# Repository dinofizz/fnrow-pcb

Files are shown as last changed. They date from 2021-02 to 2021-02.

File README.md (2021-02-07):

# FnRow

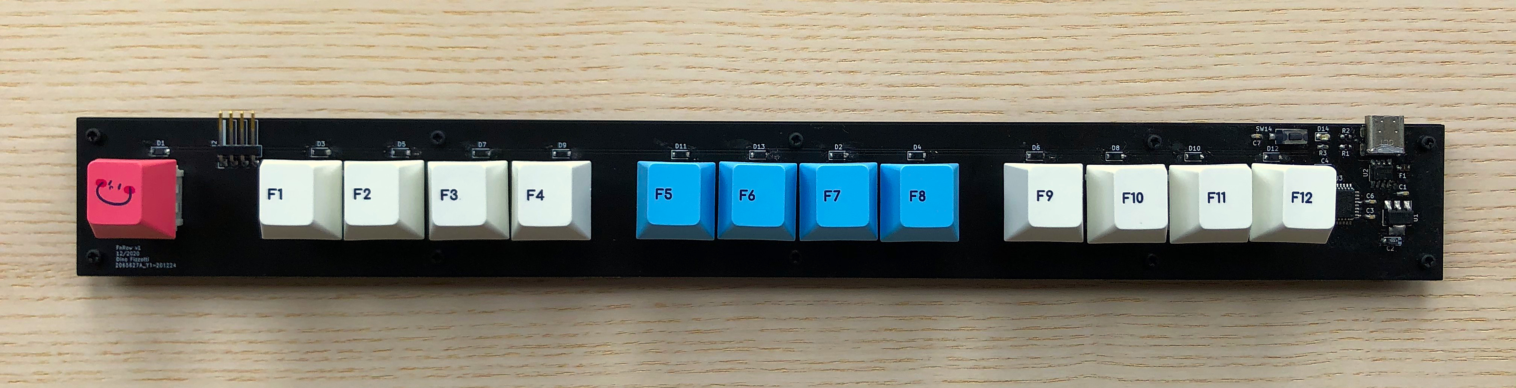
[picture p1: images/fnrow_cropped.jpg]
FnRow


FnRow is a mechanical keyboard which features a single row of switches, in the form of a "function row". Each switch is configurable and can be programmed to perform as any key on a typical keyboard, or even combinations of key presses. FnRow is akin to a "macropad", but instead of having a square or rectangular "pad", the switches are stretched out in a single row.

See more details in my blog post about this project [here](https://www.dinofizzotti.com/blog/2021-02-07-fnrow-v1-a-configurable-function-row-layout-mechanical-keyboard/).

QMK firmware [here](https://github.com/dinofizz/qmk_firmware/tree/fnrow_v1/keyboards/dinofizz/fnrow/v1).

VIA layout file [here](https://github.com/dinofizz/keyboards/tree/fnrow_v1/src/dinofizz/fnrow).

# License

FnRow by Dino Fizzotti is licensed under [Attribution-ShareAlike 4.0 International](https://creativecommons.org/licenses/by-sa/4.0/)



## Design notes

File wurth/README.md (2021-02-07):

Würth Elektronik 434121043816 CAD model copyright Octopart: https://octopart.com/434121043816-w%C3%BCrth+elektronik-23272334#CadModels

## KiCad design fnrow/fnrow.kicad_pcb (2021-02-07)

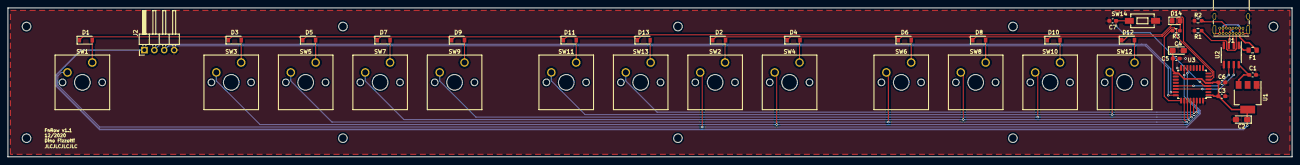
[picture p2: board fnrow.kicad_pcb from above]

Board: 4 copper layers, 328.6 x 38.1 mm, 54 parts (0 on the bottom side), 37 nets.

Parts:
C1, C3, C5, C6, C7: 100nF; C_0603_1608Metric_Pad1.08x0.95mm_HandSolder
C2: 10uF; CP_EIA-3216-12_Kemet-S_Pad1.58x1.35mm_HandSolder
C4: 4.7uF; CP_EIA-3216-12_Kemet-S_Pad1.58x1.35mm_HandSolder
D1, D2, D3, D4, D5, D6, D7, D8, D9, D10, D11, D12, D13: 1N4148; D_SOD-123
D14: LED; LED_0805_2012Metric_Pad1.15x1.40mm_HandSolder
F1: 100mA; Fuse_0805_2012Metric_Pad1.15x1.40mm_HandSolder
H1, H2, H3, H4, H5, H6, H7, H8, H9, H10: MountingHole; MountingHole_2.2mm_M2
J1: USB_C_Receptacle_USB2.0; USB_C_Receptacle_GCT_USB4085
J2: Conn_01x04; PinHeader_1x04_P2.54mm_Horizontal
R1, R2: 5k1; R_0603_1608Metric_Pad0.98x0.95mm_HandSolder
R3: 100R; R_0603_1608Metric_Pad0.98x0.95mm_HandSolder
SW1, SW2, SW3, SW4, SW5, SW6, SW7, SW8, SW9, SW10, SW11, SW12, SW13: SW_Push; SW_Cherry_MX_1.00u_PCB
SW14: SW_Push; Wuerth_Elektronik-434121043816-Manufacturer_Recommended
U1: LD1117S33TR_SOT223; SOT-223-3_TabPin2
U2: USB6B1; SOIC-8_3.9x4.9mm_P1.27mm
U3: STM32F042K6Tx; LQFP-32_7x7mm_P0.8mm

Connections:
+3V3: C2.1, C3.1, C4.1, C5.1, C6.1, J2.1, U1.2, U3.1, U3.5, U3.17
+5V: C1.1, F1.1, U1.3, U2.1, U2.8
/COL0: SW1.2, SW2.2, U3.14
/COL1: SW3.2, SW4.2, U3.15
/COL2: SW5.2, SW6.2, U3.26
/COL3: SW7.2, SW8.2, U3.27
/COL4: SW9.2, SW10.2, U3.28
/COL5: SW11.2, SW12.2, U3.29
/COL6: SW13.2, U3.30
/LED: R3.2, U3.25
/NRST: C7.1, SW14.2, U3.4
/ROW0: D1.1, D3.1, D5.1, D7.1, D9.1, D11.1, D13.1, U3.6
/ROW1: D2.1, D4.1, D6.1, D8.1, D10.1, D12.1, U3.7
/SWCLK: J2.3, U3.24
/SWDIO: J2.2, U3.23
/USB_DM: U2.6, U3.21
/USB_DP: U2.7, U3.22
GND: C1.2, C2.2, C3.2, C4.2, C5.2, C6.2, C7.2, D14.1, J1.A1, J1.A12, J1.B1, J1.B12, J1.S1, J2.4, R1.1, R2.1, SW14.1, U1.1, U2.4, U2.5, U3.16, U3.32
unnamed: D1.2, SW1.1
unnamed: D2.2, SW2.1
unnamed: D3.2, SW3.1
unnamed: D4.2, SW4.1
unnamed: D5.2, SW5.1
unnamed: D6.2, SW6.1
unnamed: D7.2, SW7.1
unnamed: D8.2, SW8.1
unnamed: D9.2, SW9.1
unnamed: D10.2, SW10.1
unnamed: D11.2, SW11.1
unnamed: D12.2, SW12.1
unnamed: D13.2, SW13.1
unnamed: D14.2, R3.1
unnamed: F1.2, J1.A4, J1.A9, J1.B4, J1.B9
unnamed: J1.A5, R1.2
unnamed: J1.A6, J1.B6, U2.2
unnamed: J1.A7, J1.B7, U2.3
unnamed: J1.B5, R2.2
